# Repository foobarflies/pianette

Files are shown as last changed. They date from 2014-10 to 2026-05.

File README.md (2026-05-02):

# Pianette = Piano + Manette

A full-fledged retro-engineering of a Playstation 2 Game Pad Controller that asynchronously listens to commands from various sources (GPIO, API, etc ...) and sends Serial commands to an `ATMEGA328P` acting as a fake SPI Slave for the Console running any configured game.

_Written in Python_

You can find more info on [this article](https://tchap.me/blog/pianette/) we wrote and on the corresponding [hacknernews discussion](https://news.ycombinator.com/item?id=9071205).

## Running Pianette

`sudo` is required to have access to GPIO pins on the **Raspberry Pi B+**.

In command line, run :

    sudo -i PYTHONIOENCODING="utf-8" ./main.py --enable-source gpio --enable-source api --select-game 'street-fighter-alpha-3' --select-player 1

> The initialisation process is quite verbose to display all warnings and errors encountered.

## Adding a new game

Games are actually Python _modules_ that are imported on-demand, with a specific configuration and directory structure.

All games reside in the `config/games` directory. The following structure must be respected :

```
config/
|-- games/
|   |-- name-of-the-game/
|   |   |-- __init__.py
|   |   |-- game.py
|   |   |-- general.ini
|   |   |-- player1.py
|   |   |-- player2.py
```

`__init__.py` must be present, but it's actually just an empty file. 

`game.py` defines custom functions that may be needed to play the game. It can be empty too. It must define functions in its global scope.

Any function defined in this file will be accessible in the `game` namespace :

```python
# file : game.py
# coding: utf-8
from pianette.utils import Debug
def my_function(*args, **kwargs):
  cmd = kwargs['cmd']
  game_configobj = kwargs['config']

  Debug.println("NOTICE", "Just playing a ✕")
  cmd.onecmd("console.play ✕")
```

This function can be called with `game.my-function optional-parameter`  or `game.my_function optional-parameter` (_we prefer and encourage the first version using hyphens_).

The config files (`.ini`) must define a couple of compulsory keys :

In `general.ini` :

```ini
[Game]

[[name-of-the-game]]

# Can be empty, but the key must be defined

[[[Mappings]]]

# Can be empty, but the key must be defined
```

In `player1.ini` and `player1.ini`:

```ini
[Game]

[[name-of-the-game]]

[[[Commands]]]

# Can be empty, but the key must be defined

[[[Player 1]]]

[[[[Mappings]]]]

# Can be empty, but the key must be defined
```

> `name-of-the-game` must be the exact name of the module folder.

With this structure, you are able to select your game with `--select-game name-of-the-game`. And with the console :

    pianette: pianette.select-game name-of-the-game

## Pianette cycles

A cycle is a **single loop during which Pianette collects events from all its enabled sources to create a complete representation of a sequence of buttons that it then sends to the SPI port of the console**.

This sequence emulates a real console controller.

The timing of the sequence is fixed and has been configured to match the behavior of the console.

To replicate the "combo" functionality (i.e. playing a sequence of buttons in a deterministic order giving a result that is more interesting than the separate playing of each buttons in a row), the loop has a grace period (_configured as a number of Pianette cycles_) during which **Pianette** listens to other incoming events to decide if the current representation should wait on future events before being sent to the console.

## Available namespaces and commands

**Pianette** allows for different namespaces of commands to be used : `console`, `game`, `piano`, `pianette` and `time`.

### console

> NB : Some character replacements are available in this namespace for ease of use. Even if actual UTF-8 values are prefered when possible, you can use the replacement without affecting the functionality. 
> 
> ↑, ↓, ←, →, □, △, ✕ and ◯ can be replaced with UP, DOWN, LEFT, RIGHT, SQUARE, TRIANGLE, CROSS and CIRCLE respectively

### `console.hit`

Plays a controller button sequence for a single **Pianette** cycle.

**Example** :

    pianette: console.hit ✕ + □

**Note** : The `+` operator is used to create a synchronous sequence of buttons

### `console.play`

Plays a controller button sequence for a full **Pianette** cycle.

**Example** :

    pianette: console.play → + □

### pianette

### `pianette.enable-source`

Enables a configured source. Once enabled, **Pianette** can accept events from the source. Currently supported sources are `api` and `gpio`.

**Example** :

    pianette: pianette.enable-source gpio

### `pianette.disable-source`

Disables a previsouly enabled and configured source. Once enabled, **Pianette** cannot accept events from this source.

> An example use case is to disable the `gpio` source when running a script along side, so the user cannot disturb the script

### `pianette.select-game`

Selects an available game. If the module is not defined or the game not present, it will gracefully fails. If the module is present but that some configuration items are missing, an exception will be raised.

**Example** :

    pianette: pianette.select-game street-fighter-alpha-3

> You must give the exact module / folder name as an argument of this function

### `pianette.dump-state`

Dumps the full state of the configuration. This is mostly a debug function; it accepts no arguments.

**Example** :

    pianette: pianette.dump-state

### piano

> NB : Some character replacements are available in this namespace for ease of use. Even if actual UTF-8 values are prefered when possible, you can use the replacement without affecting the functionality. 
> 
> Specifically, ♯ and ♭ can be replaced with # and b.
> Chords aliases are also defined in the **[[Alias]]** configuration block in `piano.ini`.

### `piano.play`

Plays a chord, a pedal or a single note.

**Example** :

    pianette: piano.play C3 + E♭3 + G3

**Note** : As for the `console` namespace, the `+` operator is used to create a synchronous sequence of keys

### `piano.hold`

Holds a note, a pedal or a chord as long as `piano.release`  is not called on the same sequence. The notes will be then added to every cycle afterwards.

**Example** :

    pianette: piano.hold sostenato

### `piano.release`

Release a previously held note, pedal or chord.

**Example** :

    pianette: piano.release sostenato

> The hold and release methods are primarily used to take advantage of the pedals.

### game

This namespace is populated with the custom functions defined in `game.py` for each game module. Commands defined in the game's configuration files are also added to this namespace.

> If no game is selected, this namespace doesn't have any command available.

### time

This namespace only provides the `time.sleep {duration_in_pianette_cycles}` function that allows to pace the inputs as needed.

## The Pianette API

Pianette exposes an API

> The API is considered a source, so in order for it to work, you must enable it at launch or with the command `pianette.enable-source api`.

By default, the API base url is `http://127.0.0.1:5000/`. You can change the port in the configuration (`pianette.ini`).

### Endpoints

#### POST `/`

The endpoint is relatively simple and allows you to send any namespaced command as a POST parameter named `data`:

      curl -X POST -F 'data=console.play START + RESET' /

#### POST `/namespace/command`

This endpoint is a kind of alias for the first one. It allows you to limit the errors and send strongly-namespaced commands more easily.

      curl -X POST -F 'data=crash-nitro-kart' /pianette/select-game

### The web interface

The web interface relies on the API to work, and thus is only available when the API is enabled. It offers a backend to control pianette, as well as virtual controllers that can be used to play remotely on the console.

> In order for the web interface to work properly, the `[[Hosts]]` key of `pianette.ini` must be defined and the IP (or hostname) of the different pianette instances on the network must be set. If you only have one instance, you can define `player-1 = 127.0.0.1` only.

#### The virtual controller

The virtual controller is a #TODO

#### The admin backend

TODO

## Installation

### ATMEGA (Arduino)

The `ArduinoSPISlave.ino` sketch must be loaded onto the Arduino, connected via serial. The port is of no consequence as the program will poll the open `/dev/ttyACM*`ports and choose the first one available.

### Blacklisting

In order for SPI and i2c pins to work, it is compulsory to blacklist all modules that might be using it :

in `/etc/modprobe.d/raspi-blacklist.conf` :

    blacklist spi-bcm2708
    blacklist i2c-bcm2708

    blacklist regmap-spi
    blacklist regmap-i2c

    blacklist snd-pcm
    blacklist snd-bcm2835
    blacklist snd-seq
    blacklist snd-timer
    blacklist snd-seq-device
    blacklist snd-soc-core
    blacklist snd-soc-pcm512x
    blacklist snd-soc-wm8804
    blacklist snd-soc-bcm2708-i2s

    blacklist leds-gpio

And to remove modules at boot time in `/etc/modules`, especially sound-related modules.

### Disabling Serial port pins (UART)

In order to properly use pins `14`, `15`, and `18` that are used for `UART`, we must disable the boot up and diagnostic output to the serial port :

    sudo vi /boot/cmdline.txt

This :

    dwc_otg.lpm_enable=0 console=ttyAMA0,115200 console=tty1 root=/dev/mmcblk0p2 rootfstype=ext4 elevator=deadline rootwait fbcon=map:10 4dpi.sclk=48000000 4dpi.compress=1

becomes :

    dwc_otg.lpm_enable=0 console=tty1 root=/dev/mmcblk0p2 rootfstype=ext4 elevator=deadline rootwait fbcon=map:10 4dpi.sclk=48000000 4dpi.compress=1

Second, we need to disable the login prompt :

    sudo vi /etc/inittab

And comment out the last line :

    # Spawn a getty on Raspberry Pi serial line
    # T0:23:respawn:/sbin/getty -L ttyAMA0 115200 vt100

Let's reboot and the serial port will now be free for our exclusive use. Note that Python will still issue a `RuntimeWarning` to indicate that you are overriding the pin's default state. This is ok, and taken into account in `sources/gpio.py` anyway. 

>  Thanks to **Ted B Hale** for that : _http://raspberrypihobbyist.blogspot.fr/2012/08/raspberry-pi-serial-port.html_

### Installing needed pip packages

The necessary Python packages have been freezed, so you can install them easily with :

    pip install -r requirement.txt

And additionnally on the Pi :
    
    pip install -r requirement-rpi.txt

### Installing Pianette as a service

For ease of use, we provide a simple init script to start Pianette as a service on compatible systems :

    sudo service pianette start|stop|restart|status

See the `pianette_initd_script.sh` script, to put in `/etc/init.d/` or wherever seems adequate.

### Limitations

#### Python version

For [Flask](https://flask.palletsprojects.com/en/1.1.x/) to run correctly, we need **Python3.3.6**. It is recommended to use **pyenv** to use it, which can be installed via :

    curl -L https://raw.githubusercontent.com/yyuu/pyenv-installer/master/bin/pyenv-installer | bash

and then :

    pyenv install 3.3.6

## Team

  - **Coox** — [https://coox.org](https://coox.org)
  - **Tchap** — [https://tchap.me](https://tchap.me)

## License

**MIT**. See the [License file](https://github.com/tchapi/pianette/blob/master/LICENSE).

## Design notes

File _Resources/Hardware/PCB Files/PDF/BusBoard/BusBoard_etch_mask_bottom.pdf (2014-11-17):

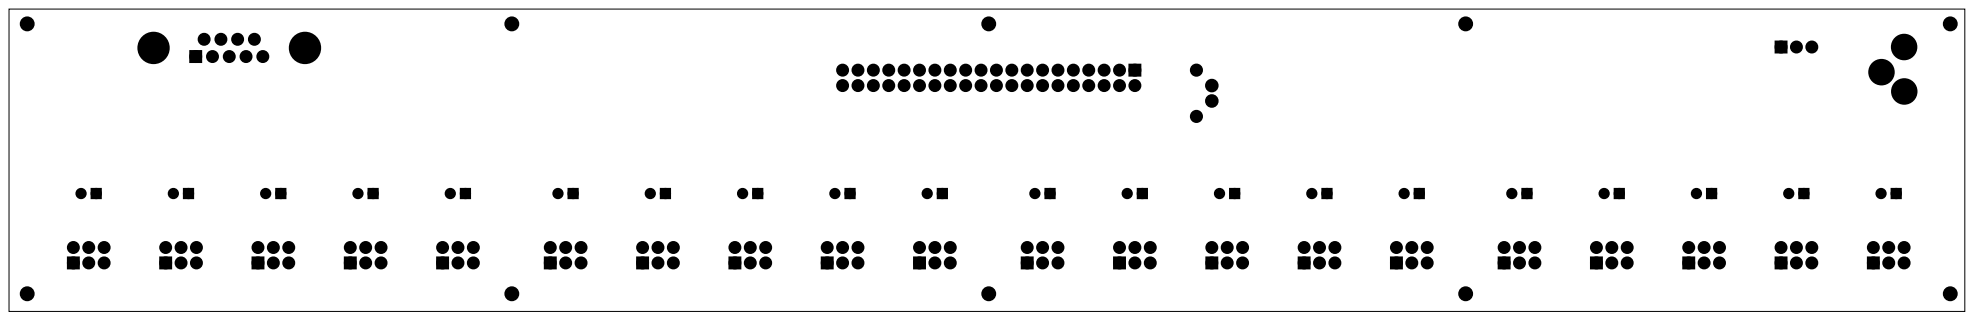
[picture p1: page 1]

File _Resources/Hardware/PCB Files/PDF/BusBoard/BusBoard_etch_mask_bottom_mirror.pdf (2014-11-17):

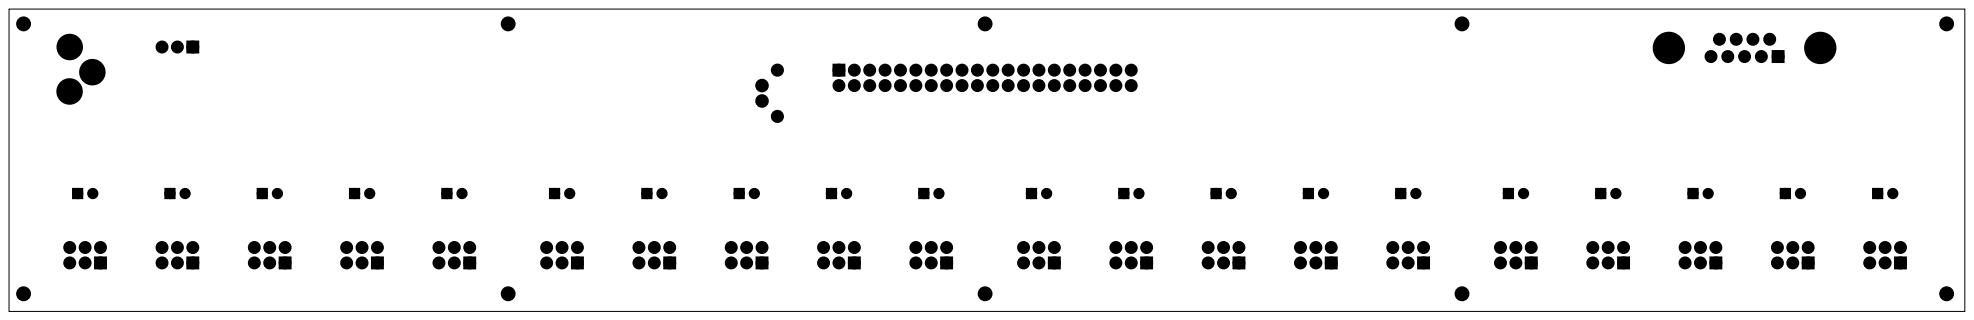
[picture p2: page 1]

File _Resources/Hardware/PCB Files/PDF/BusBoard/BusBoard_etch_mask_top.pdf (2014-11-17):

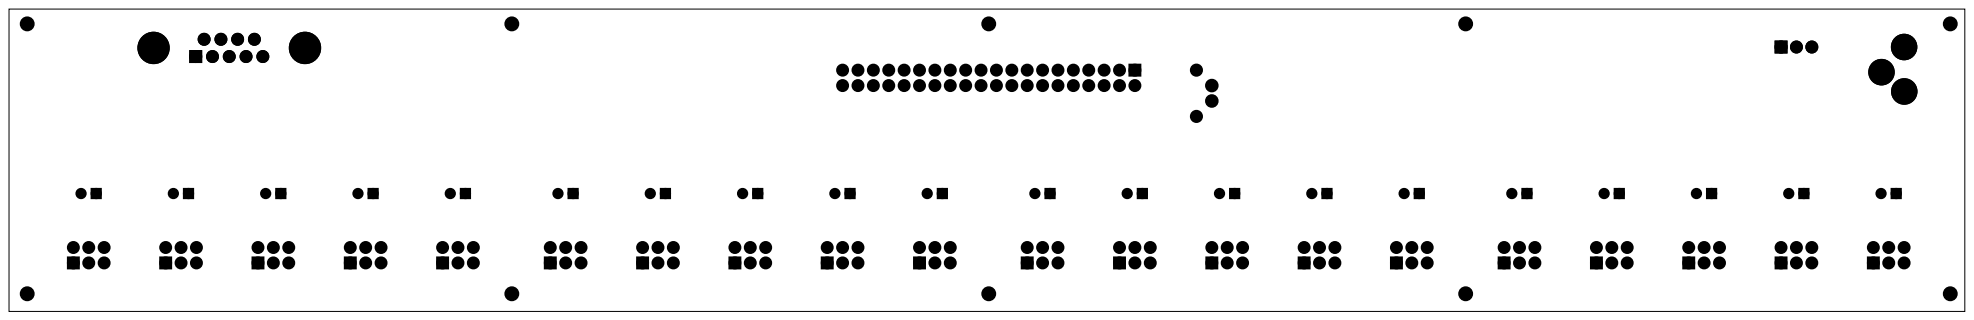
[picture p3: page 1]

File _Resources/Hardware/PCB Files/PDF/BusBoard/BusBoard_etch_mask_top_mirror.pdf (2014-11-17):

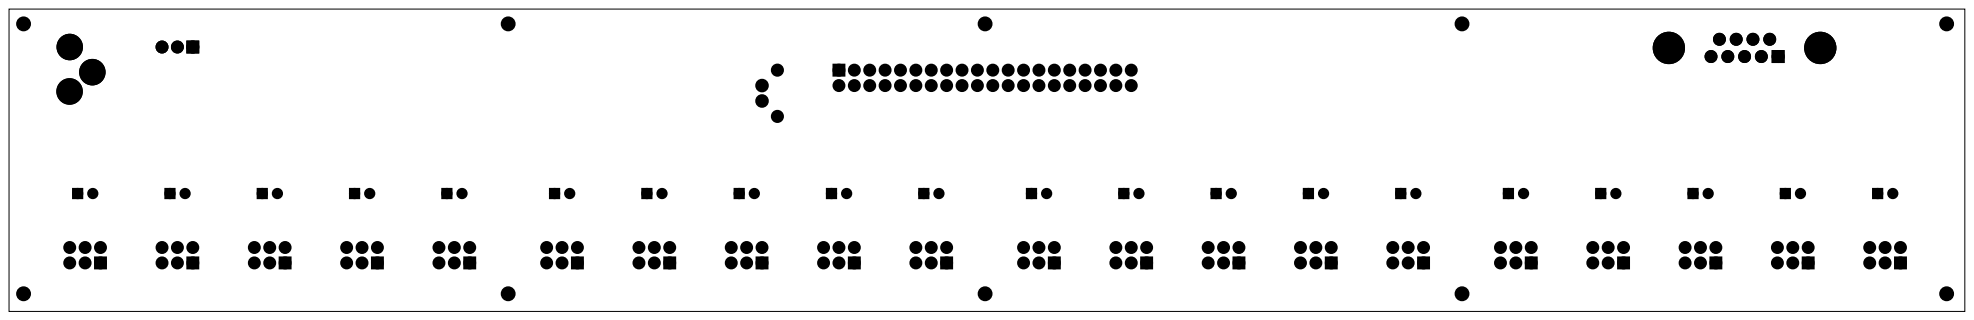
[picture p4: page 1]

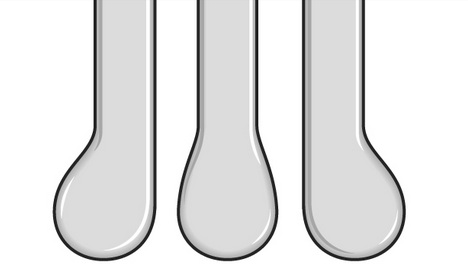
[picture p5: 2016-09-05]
_Resources/Mappings/Piano drawings/pedals.png

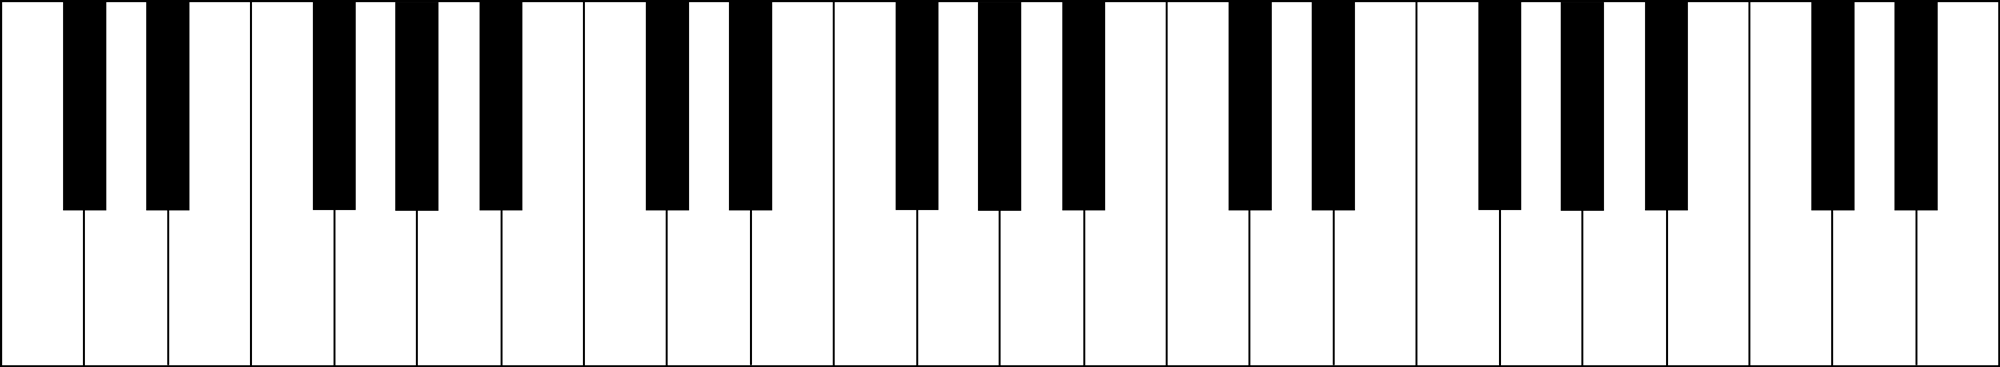
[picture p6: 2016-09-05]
_Resources/Mappings/Piano drawings/keyboard.png

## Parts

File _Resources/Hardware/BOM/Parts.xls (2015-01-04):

All products parts are listed on sparkfun.com | https://www.sparkfun.com | https://www.sparkfun.com | https://www.sparkfun.com | https://www.sparkfun.com
Description |  | Product # | Qty | Total Price
Pianette
 | Raspberry Pi B+ - GPIO Shrouded Header (2x20) | PRT-13054 | 2 | 1.52 €
 | DC Barrel Power Jack/Connector | PRT-00119 | 2 | 2.00 €
Raspberry pi
 | Raspberry Pi - Model B+ | DEV-12994 | 2 | 63.82 €
 | Raspberry Pi - Model B+ Enclosure (Clear) | DEV-12996 | 2 | 14.30 €
 | Raspberry Pi - 8GB SD Card | DEV-12998 | 2 | 19.10 €
 | Raspberry Pi B+ - GPIO Ribbon Cable (40-pin, 6") | CAB-13028 | 2 | 3.99 €
SPI Controller
 | Arduino Uno - R3 | DEV-11021 | 2 | 39.86 €
 | USB Cable A to B - 6 Foot | CAB-00512 | 2 | 6.32 €
Triggers
 | Resistor 1.0M Ohm 1/4 Watt PTH | COM-11853 | 40 | 4.47 €
 | LED - Basic Green 3mm | COM-09650 | 40 | 10.22 €
 | LED - Basic Red 3mm | COM-00533 | 40 | 10.22 €
 | Zener Diode - 5.1V 1W | COM-10301 | 40 | 7.35 €
 | Piezo Vibration Sensor - Small Vertical | SEN-09199 | 40 | 84.99 €
 | Op-Amp (Thru-Hole) - LM358 | COM-09456 | 40 | 27.48 €
 | JST Jumper 2 Wire Assembly | PRT-09914 | 40 | 27.48 €
 | Ribbon Cable - 6 wire (3ft) | CAB-10648 | 12 | 7.18 €
 | DIP Sockets Solder Tail - 8-Pin | PRT-07937 | 40 | 14.38 €
 | 2x3 Pin Shrouded Header | PRT-10877 | 80 | 86.40 €
 | Ribbon Crimp Connector - 6-pin (2x3, Female) | PRT-10651 | 80 | 20.80 €
Big red button
 | Big Dome Pushbutton - Red | COM-09181 | 1 | 7.95 €
 | Microswitch - 3-terminal | COM-09506 | 1 | 1.20 €
 |  | TOTAL |  | 461.03 €

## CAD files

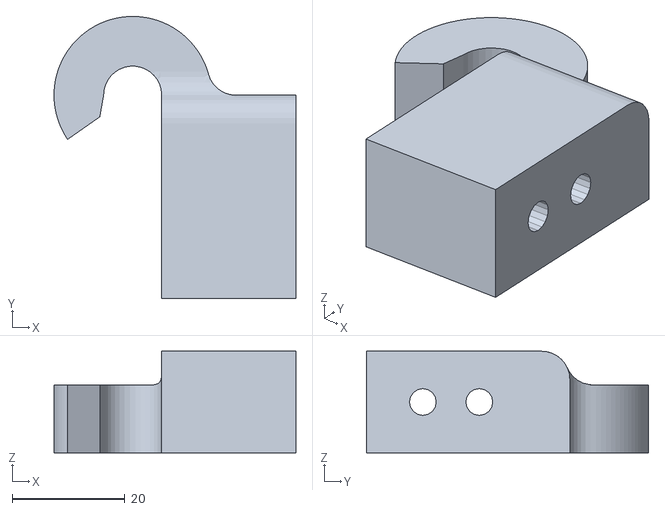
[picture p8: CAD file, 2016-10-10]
_Resources/Hardware/3D Printed parts/Piano/STL/Export_WEBER_Left.stl
42.9 x 50.0 x 18.0

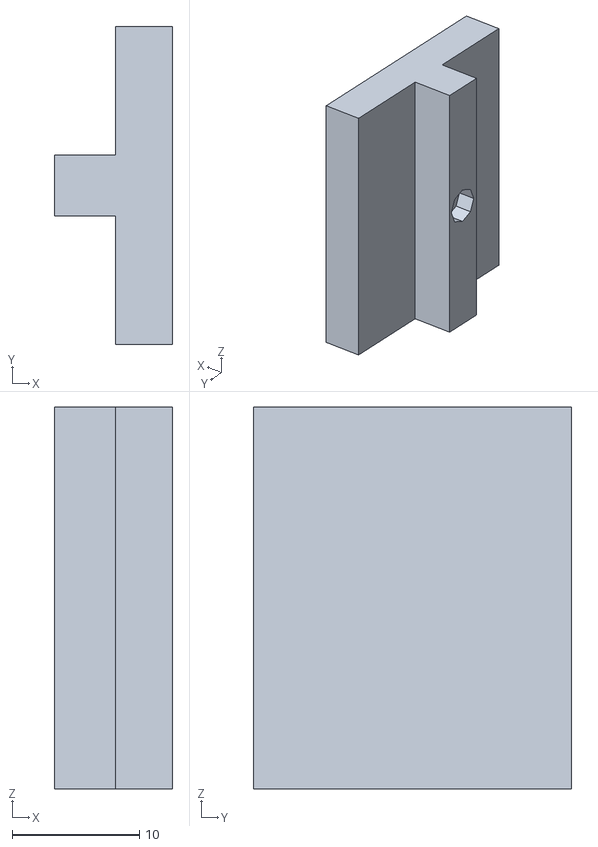
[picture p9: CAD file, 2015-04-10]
_Resources/Hardware/3D Printed parts/Piano/STL/Other pianos/cale_5mm.stl
9.30 x 25.0 x 30.0

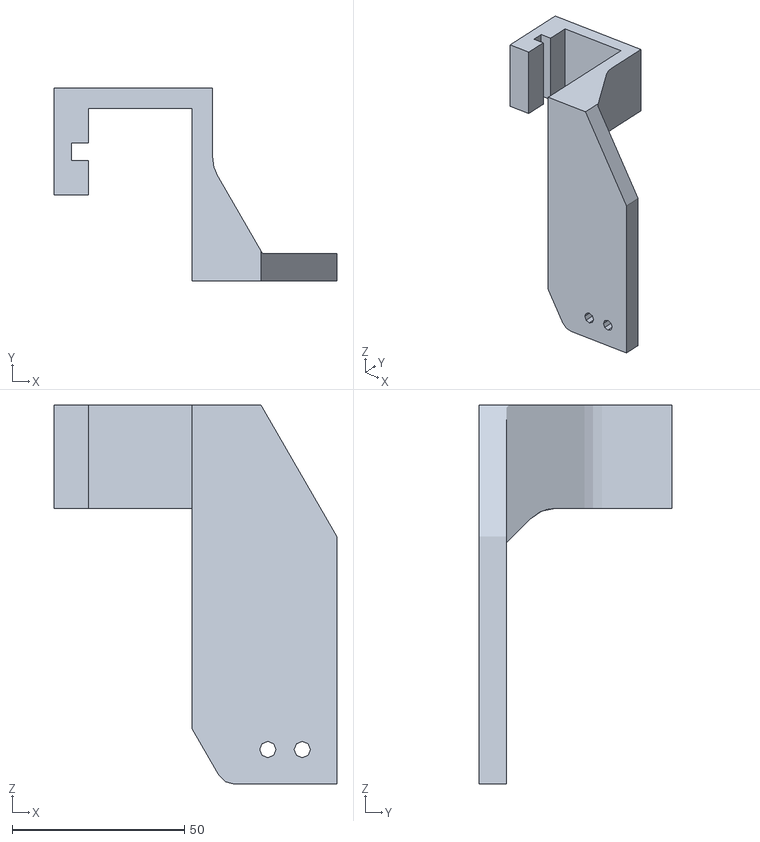
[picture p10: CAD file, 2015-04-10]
_Resources/Hardware/3D Printed parts/Piano/STL/Other pianos/piano_right.stl
82.0 x 56.0 x 110.0

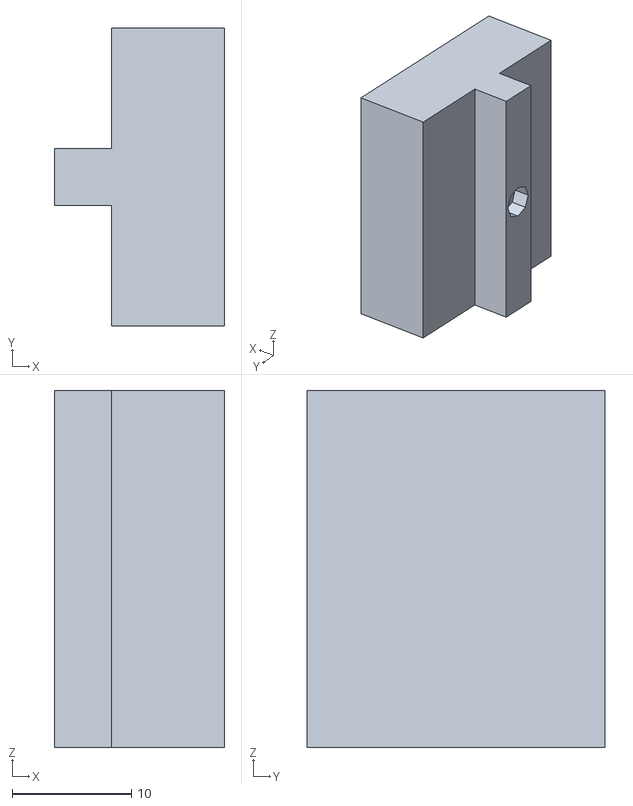
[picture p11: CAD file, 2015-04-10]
_Resources/Hardware/3D Printed parts/Piano/STL/Other pianos/cale_10mm.stl
14.3 x 25.0 x 30.0

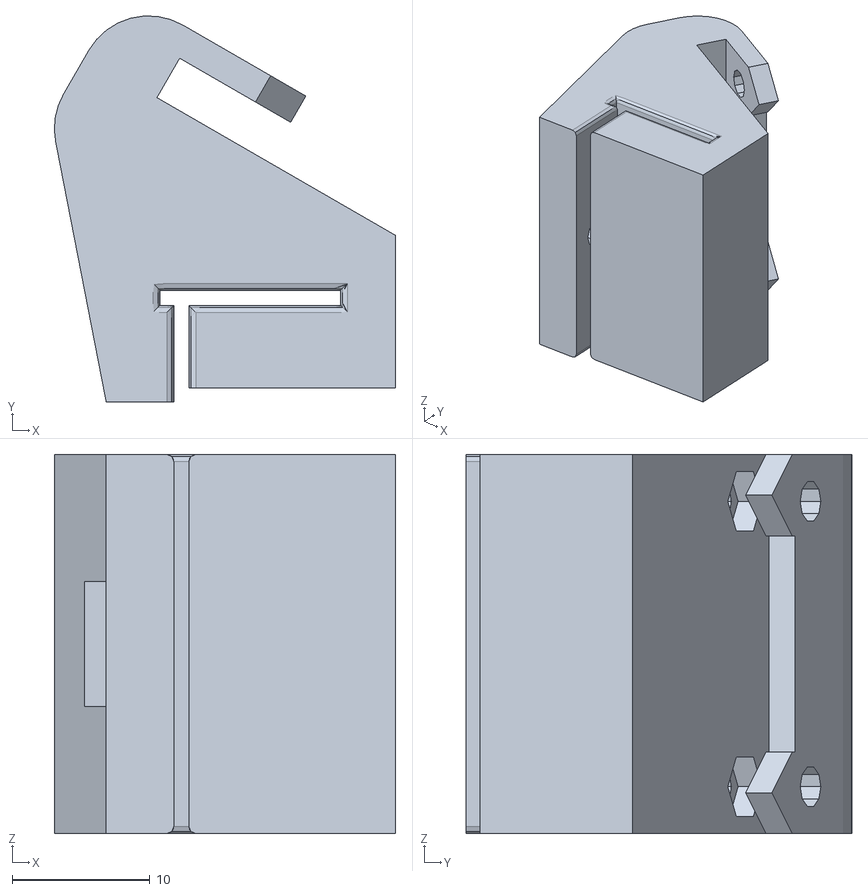
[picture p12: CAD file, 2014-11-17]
_Resources/Hardware/3D Printed parts/Piano/STL/Slider.stl
24.8 x 28.0 x 27.5

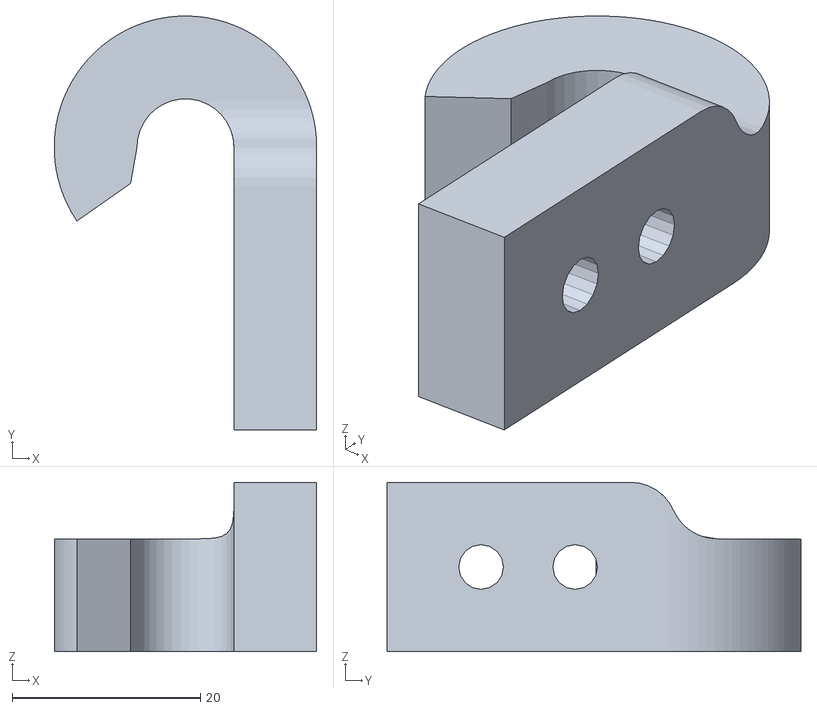
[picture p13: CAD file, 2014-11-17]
_Resources/Hardware/3D Printed parts/Piano/STL/Left Hook.stl
27.9 x 44.0 x 18.0

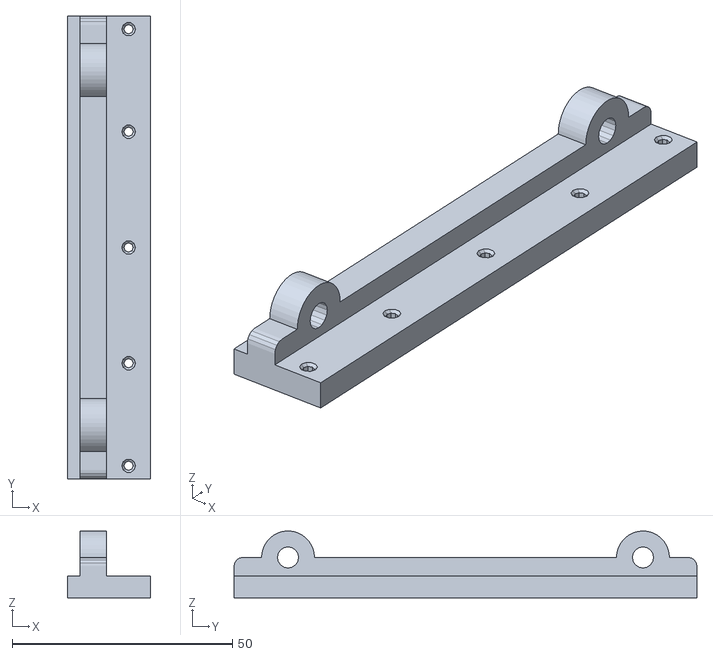
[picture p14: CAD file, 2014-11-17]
_Resources/Hardware/3D Printed parts/Piano/STL/Pianette Holder.stl
18.9 x 105.0 x 15.2

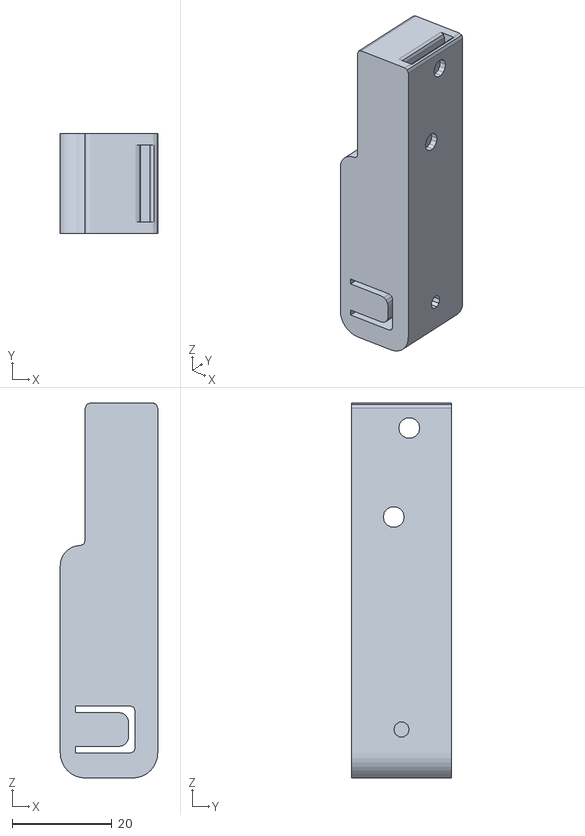
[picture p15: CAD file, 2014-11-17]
_Resources/Hardware/3D Printed parts/Piano/STL/Rail Holder.stl
19.5 x 20.0 x 75.0

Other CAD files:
_Resources/Hardware/3D Printed parts/Piano/STL/Export_WEBER_Right.stl
_Resources/Hardware/3D Printed parts/Piano/STL/Right Hook.stl
_Resources/Hardware/3D Printed parts/Piano/Hooks_Weber.CATPart

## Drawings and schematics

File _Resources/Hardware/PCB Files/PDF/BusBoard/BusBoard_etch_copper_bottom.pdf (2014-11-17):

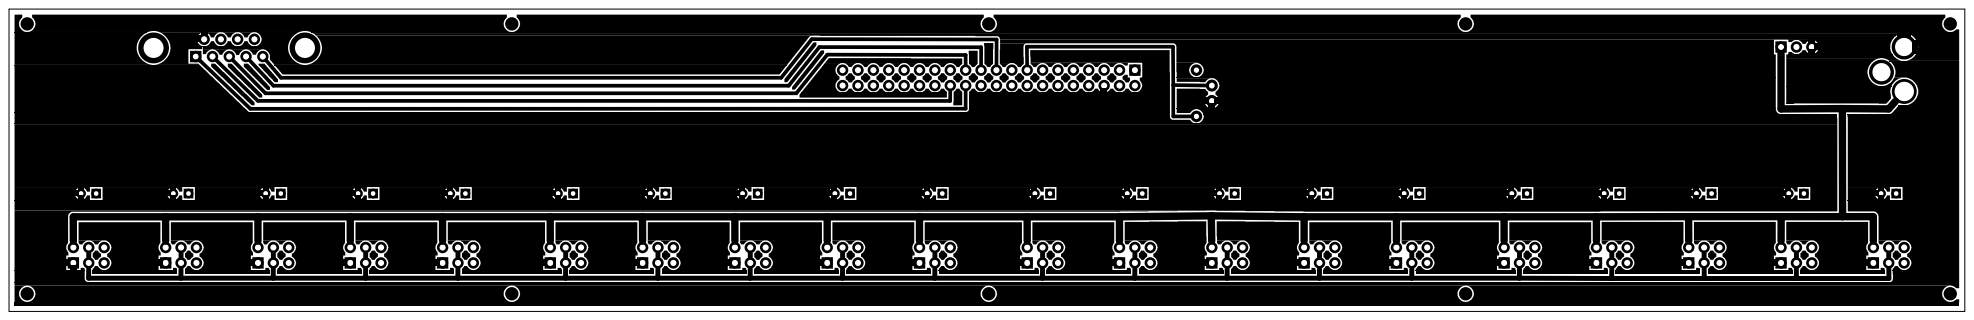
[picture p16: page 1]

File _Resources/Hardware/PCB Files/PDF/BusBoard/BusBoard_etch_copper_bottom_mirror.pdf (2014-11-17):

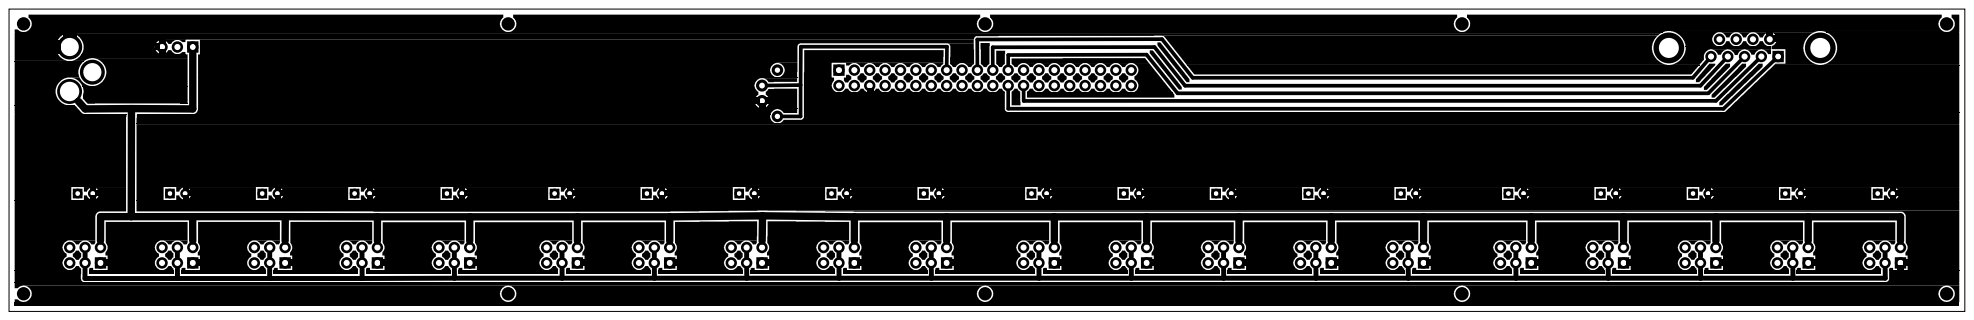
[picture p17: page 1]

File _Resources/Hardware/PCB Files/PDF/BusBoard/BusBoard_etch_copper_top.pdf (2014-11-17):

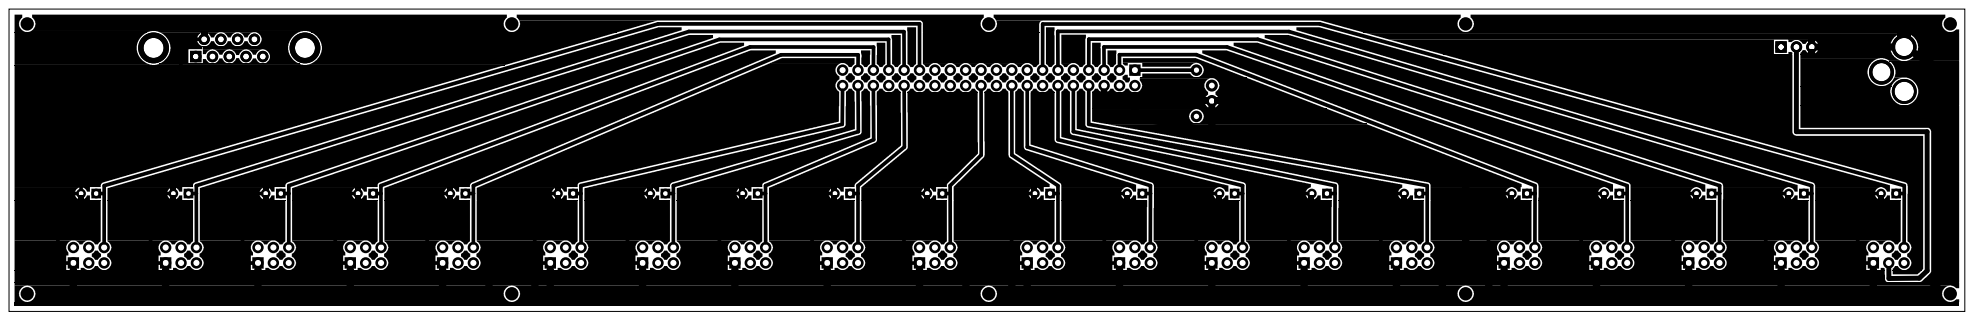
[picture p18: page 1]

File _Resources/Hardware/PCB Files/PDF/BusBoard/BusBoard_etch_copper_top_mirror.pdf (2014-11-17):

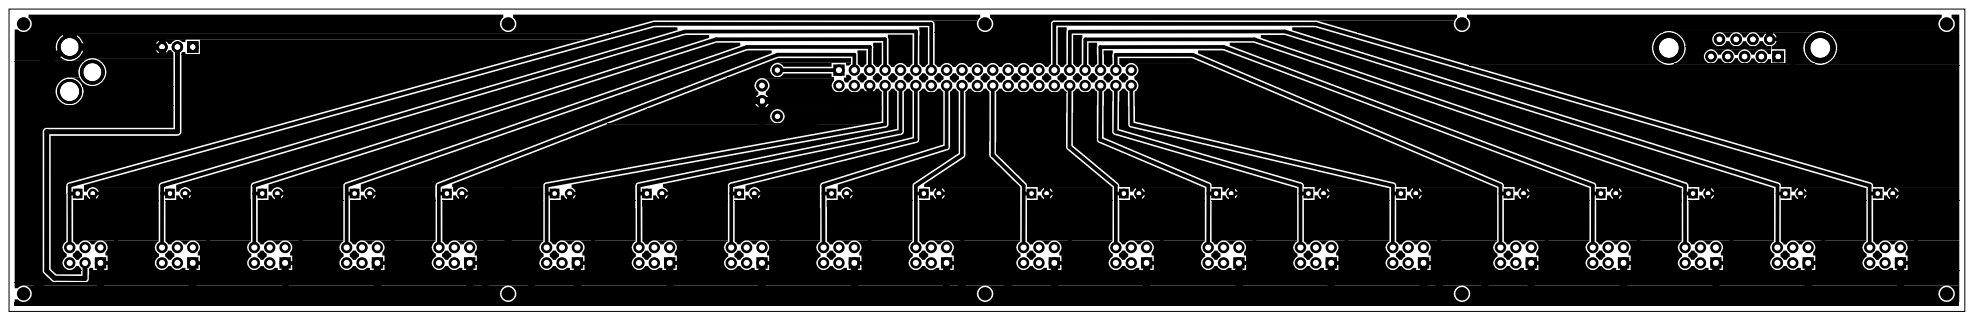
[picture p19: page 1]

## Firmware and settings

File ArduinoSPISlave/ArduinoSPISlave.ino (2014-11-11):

/*

Arduino SPI Slave for Playstation 2

Based on busslave's work form 2012
 
Arduino pin |  AVR pin | PSX pin

9 PB1       |    15    | 9 ACK     (green)
10 -SS      |    16    | 6 ATT     (yellow)
11 MOSI     |    17    | 2 COMMAND (orange)
12 MISO     |    18    | 1 DATA    (brown)
13 SCK      |    19    | 7 CLOCK   (blue)
                       | 4 GND
*/

#include "Arduino.h"
#include <avr/io.h>
#include <avr/interrupt.h>
#include <util/delay.h>

#define F_CPU 16000000
#define ARDUINO 101

#define SPI_PORT PORTB
#define SPI_PINS PINB
#define SPI_DDR  DDRB
#define SPI_PINS  PINB

#define ACK_PIN   1 //PB1
#define ATT_PIN   2 //~SS
#define CMD_PIN   3 //MOSI
#define DATA_PIN  4 //MISO
#define CLK_PIN   5 //SCK

#define DATA_LEN 5

#define LED_PIN 7

#define _DEBUG 0

char control_data[2] = {0xFF,0xFF};

volatile uint8_t data_buff[DATA_LEN]={0x41,0x5A,0xFF,0xFF,0xFF}; // Reply: nothing pressed.
volatile uint8_t command_buff[DATA_LEN]={0x01,0x42,0x00,0x00,0x00};
    
volatile uint8_t curr_byte=0;
volatile uint8_t next_byte=0;

void setup();
void loop();

void setup() {
  
  // Begin Serial communication with Pi
  Serial.begin(38400);
    
  //SPI_PORT setup. 
  SPI_DDR |= (1<<ACK_PIN); // output
  SPI_PORT |= (1<<ACK_PIN); // set HIGH
  SPI_DDR |= (1<<DATA_PIN); // output
  SPI_PORT |= (1<<DATA_PIN); // set HIGH  
  
  //SPI setup.
  PRR &= ~(1<<PRSPI);  // Set to 0 to ensure power to SPI module.
  SPSR|=(1<<SPI2X);    // Fosc/32. @16MHz==500KHz.
  //SPCR|=(1<<SPR1);   // Fosc/64. @16MHz==250KHz.
  SPCR|=(1<<CPHA);     // Setup @ leading edge, sample @ falling edge.
  SPCR|=(1<<CPOL);     // Leading edge is falling edge, trailing edge is rising edge.
  SPCR &= ~(1<<MSTR);  // MSTR bit is zero, SPI is slave.
  SPCR|=(1<<DORD);     // Byte is transmitted LSB first, MSB last.
  SPCR|=(1<<SPE);      // Enable SPI.
  SPCR|=(1<<SPIE);     // Enable Serial Transfer Complete (STC) interrupt.
  SPDR=0xFF;
  
  sei(); // Enable global interrupts.

  // Indicate Reset
  pinMode(LED_PIN, OUTPUT);
  digitalWrite(LED_PIN, HIGH);
  delay(500);
  digitalWrite(LED_PIN, LOW);
  delay(70);
  digitalWrite(LED_PIN, HIGH);
  delay(70);
  digitalWrite(LED_PIN, LOW);
  delay(70);
  digitalWrite(LED_PIN, HIGH);
  delay(70);
  digitalWrite(LED_PIN, LOW);
  delay(70);
  digitalWrite(LED_PIN, HIGH);
  delay(70);
  digitalWrite(LED_PIN, LOW);

  if (_DEBUG) {
    Serial.println("");
    Serial.println("-----------------------------------");
    Serial.println("Playstation 2 Protocol initialized.");
    Serial.println("-----------------------------------");
  }

}

/* SPI interrupt */
ISR(SPI_STC_vect) { 

  // Byte received from the master
  uint8_t inbyte = SPDR;
  
  // FIX ME : Manage other cases ? (other commands from the master?)
  if (inbyte == command_buff[curr_byte]) {

    // We put the next byte in the buffer, to be send along the next clock cycle
    SPDR = data_buff[curr_byte];
    curr_byte++;
    
    // We need to ACK (PS2 Protocol)
    if (curr_byte < DATA_LEN) { // ACK goes low.
      SPI_PORT &= ~(1<<PORTB1);
      _delay_us(10); // For 10µseconds
      SPI_PORT |= (1<<PORTB1);
    } else { // Except for the last packet
      SPDR = 0xFF;
      curr_byte = 0;
    }

  } else {
    
    SPDR = 0xFF;
    curr_byte = 0;
  
  }
  
}

void loop() {

  /* Reads input from Serial connection */
  /*
    We're going to read 2 characters = 2 x 1 byte
    It's going to be read as a char but then translated
    to HEX, taking only the lower byte
  */

  if (Serial.available() >= 2) {
    
    Serial.readBytes(control_data, 2); // Read 16 bits

    // DEBUG 
    if (_DEBUG) {
      Serial.print("Command : 0x");
      Serial.print(lowByte(control_data[0]), HEX);
      Serial.print(" 0x");
      Serial.print(lowByte(control_data[1]), HEX);
      Serial.println("");
    }

    // We store the new commands in the data_buff buffer
    data_buff[2] = lowByte(control_data[0]);
    data_buff[3] = lowByte(control_data[1]);

    // Led
    if (lowByte(control_data[0]) != 255 || lowByte(control_data[1]) != 255){
      digitalWrite(LED_PIN, HIGH);
    } else {
      digitalWrite(LED_PIN, LOW);
    }
    
  }

}

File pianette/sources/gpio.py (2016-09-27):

# coding: utf-8

import pianette.errors
import re
import time
import warnings

from pianette.utils import Debug

import RPi.GPIO

RPi.GPIO.setwarnings(True)
RPi.GPIO.cleanup()

class GPIOConfigUtil:

    # Channels

    CHANNEL_LABELING_BCM = "BCM"

    supported_channel_labelings = [ CHANNEL_LABELING_BCM ]

    @staticmethod
    def is_supported_channel_labeling(channel_labeling):
        return channel_labeling in GPIOConfigUtil.supported_channel_labelings

    rpi_gpio_mode_for_channel_labeling = {
        CHANNEL_LABELING_BCM: RPi.GPIO.BCM,
    }

    @staticmethod
    def get_rpi_gpio_mode_for_channel_labeling(channel_labeling):
        if not GPIOConfigUtil.is_supported_channel_labeling(channel_labeling):
            raise PianetteGPIOConfigError("Unsupported GPIO channel labeling '%s'" % (channel_labeling))

        if channel_labeling not in GPIOConfigUtil.rpi_gpio_mode_for_channel_labeling.keys():
            raise PianetteGPIOConfigError("Undefined GPIO mode for channel labeling '%s'" % (channel_labeling))

        return GPIOConfigUtil.rpi_gpio_mode_for_channel_labeling.get(channel_labeling, None)

    @staticmethod
    def get_rpi_gpio_channel(channel, channel_labeling):
        if not GPIOConfigUtil.is_supported_channel_labeling(channel_labeling):
            raise PianetteGPIOConfigError("GPIO channel labeling '%s' is not supported" % (channel_labeling))

        rpi_gpio_channel = None

        if channel_labeling == GPIOConfigUtil.CHANNEL_LABELING_BCM:
            match = re.search('GPIO(?P<rpi_gpio_channel>\d+)', channel)
            if match:
                rpi_gpio_channel = int(match.group('rpi_gpio_channel'))

        if rpi_gpio_channel is None:
            raise PianetteConfigError("Undefined RPi.GPIO channel for channel '%s' using labeling '%s'" % (channel, channel_labeling))

        return rpi_gpio_channel

    # Resistors

    RESISTOR_PULL_DOWN = "pull-down"
    RESISTOR_PULL_UP = "pull-up"
    RESISTOR_NONE = "none"

    supported_resistors = [ RESISTOR_PULL_DOWN, RESISTOR_PULL_UP, RESISTOR_NONE ]

    @staticmethod
    def is_supported_resistor(resistor):
        return resistor in GPIOConfigUtil.supported_resistors

    rpi_gpio_pull_up_down_for_resistor = {
        RESISTOR_PULL_DOWN: RPi.GPIO.PUD_DOWN,
        RESISTOR_PULL_UP: RPi.GPIO.PUD_UP,
        RESISTOR_NONE: None,
    }

    @staticmethod
    def get_rpi_gpio_pull_up_down_for_resistor(resistor):
        if not GPIOConfigUtil.is_supported_resistor(resistor):
            raise PianetteGPIOConfigError("Unsupported GPIO resistor '%s'" % (resistor))

        if resistor not in GPIOConfigUtil.rpi_gpio_pull_up_down_for_resistor.keys():
            raise PianetteGPIOConfigError("Undefined GPIO pull-up-down for resistor '%s'" % (resistor))

        return GPIOConfigUtil.rpi_gpio_pull_up_down_for_resistor.get(resistor, None)

    # Events

    EVENT_FALLING = "Falling"
    EVENT_RISING = "Rising"

    supported_events = [ EVENT_FALLING, EVENT_RISING ]

    @staticmethod
    def is_supported_event(event):
        return event in GPIOConfigUtil.supported_events

    rpi_gpio_event_for_event = {
        EVENT_FALLING: RPi.GPIO.FALLING,
        EVENT_RISING: RPi.GPIO.RISING,
    }

    @staticmethod
    def get_rpi_gpio_event_for_event(event):
        if not GPIOConfigUtil.is_supported_event(event):
            raise PianetteGPIOConfigError("Unsupported GPIO event '%s'" % (event))

        if event not in GPIOConfigUtil.rpi_gpio_event_for_event.keys():
            raise PianetteGPIOConfigError("Undefined GPIO event for event '%s'" % (event))

        return GPIOConfigUtil.rpi_gpio_event_for_event.get(event, None)

    # Polling

    POLLING_STATUS_HIGH = "High"
    POLLING_STATUS_LOW = "Low"

    supported_polling_statuses = [ POLLING_STATUS_HIGH, POLLING_STATUS_LOW ]

    @staticmethod
    def is_supported_polling_status(polling_status):
        return polling_status in GPIOConfigUtil.supported_polling_statuses

    rpi_gpio_input_for_polling_status = {
        POLLING_STATUS_HIGH: RPi.GPIO.HIGH,
        POLLING_STATUS_LOW: RPi.GPIO.LOW,
    }

    @staticmethod
    def get_rpi_gpio_input_for_polling_status(polling_status):
        if not GPIOConfigUtil.is_supported_polling_status(polling_status):
            raise PianetteGPIOConfigError("Unsupported GPIO polling status '%s'" % (polling_status))

        if polling_status not in GPIOConfigUtil.rpi_gpio_input_for_polling_status.keys():
            raise PianetteGPIOConfigError("Undefined GPIO input for polling status '%s'" % (polling_status))

        return GPIOConfigUtil.rpi_gpio_input_for_polling_status.get(polling_status, None)

    POLLING_EVENT_FALLING = "Falling"
    POLLING_EVENT_RISING = "Rising"

    supported_polling_events = [ POLLING_EVENT_FALLING, POLLING_EVENT_RISING ]

    @staticmethod
    def is_supported_polling_event(polling_event):
        return polling_event in GPIOConfigUtil.supported_polling_events
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

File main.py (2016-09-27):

#!/usr/bin/env python3

# Pianette

# A command-line emulator of a PS2 Game Pad Controller 
# that asynchronously listens to GPIO EDGE_RISING
# inputs from sensors and sends Serial commands to 
# an ATMEGA328P acting as a fake SPI Slave for the Console.

# Written in Python 3.

import importlib
import pianette.config
import sys

from pianette.Pianette import Pianette
from pianette.PianetteArgumentParser import PianetteArgumentParser
from pianette.utils import Debug

Debug.println("INFO", " ")
Debug.println("INFO", " ################################## ")
Debug.println("INFO", " |            PIANETTE            | ")
Debug.println("INFO", " ################################## ")
Debug.println("INFO", " ")

configobj = pianette.config.get_all_configobj()

parser = PianetteArgumentParser(configobj=configobj)
args = parser.parse_args()

# Instanciate the global Pianette
# Its responsibility is to translate Piano actions to Console actions
pianette = Pianette(configobj=configobj)

# We MUST select a player before we select a game.
# This allow for per-player mappings
# The game can be changed afterwards, but not the player, as we don't expect
# to be able to unplug the controller from the console.
pianette.select_player(args.selected_player)
pianette.select_game(args.selected_game)

if args.enabled_sources is not None:
    for source in args.enabled_sources:
        pianette.load_source(source)

# Run the main loop of interactive Pianette
Debug.println("NOTICE", "Entering main loop")
pianette.cmd.cmdloop()

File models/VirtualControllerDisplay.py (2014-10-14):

from utils import *
from tkinter import *

class VirtualControllerDisplay(Frame):

  def __init__(self, base, stateController):
    super(VirtualControllerDisplay, self).__init__(base)

    self.stateController = stateController
    self.base = base # appWindow

    self.grid()
    self.createButtons()
    self.createUtilityButtons()
    Debug.println("SUCCESS", "Gui created.")

  def createUtilityButtons(self):
# Quit button
    self.BUTTON_QUIT = Button(self)
    self.BUTTON_QUIT["text"] = "Quit"
    self.BUTTON_QUIT["command"] = lambda: self.base.destroy()
    self.BUTTON_QUIT.grid(row=7, column=5)

# Reset button
    self.BUTTON_RESET = Button(self)
    self.BUTTON_RESET["text"] = "Reset"
    self.BUTTON_RESET["command"] = lambda: self.buttonAction("RESET")  
    self.BUTTON_RESET.grid(row=7, column=6)

# Label for commands
    self.LABEL_CMD = Label(self)
    self.LABEL_CMD["text"] = "..."
    self.LABEL_CMD["relief"] = SUNKEN
    self.LABEL_CMD["font"] = ('Helvetica', '16')
    self.LABEL_CMD.grid(row=1, column=5	, columnspan=2, padx=1, pady=1, sticky="we")

# Placeholder for swag
    self.LABEL_PLACEHOLDER = Label(self)
    self.LABEL_PLACEHOLDER["text"] = "  "
    self.LABEL_PLACEHOLDER.grid(row=0, column=4	, columnspan=2)

# Placeholder for swag
    self.LABEL_PLACEHOLDER = Label(self)
    self.LABEL_PLACEHOLDER["text"] = "  "
    self.LABEL_PLACEHOLDER.grid(row=2, column=4	, columnspan=2)

# Placeholder for swag
    self.LABEL_PLACEHOLDER = Label(self)
    self.LABEL_PLACEHOLDER["text"] = "  "
    self.LABEL_PLACEHOLDER["font"] = ('Helvetica', '30')
    self.LABEL_PLACEHOLDER.grid(row=6, column=4	, columnspan=2)

  def createButtons(self):

# O Button
    self.BUTTON_O = Button(self)
    self.BUTTON_O["bg"] = "darkGray"
    self.BUTTON_O["activebackground"] = "darkGray"
    self.BUTTON_O["fg"] = "red"
    self.BUTTON_O["height"] = 1
    self.BUTTON_O["width"] = 1
    self.BUTTON_O["text"] = "◯"
    self.BUTTON_O["command"] = lambda: self.buttonAction("O")
    self.BUTTON_O.grid(row=4, column=9)
# X Button
    self.BUTTON_X = Button(self)
    self.BUTTON_X["bg"] = "darkGray"
    self.BUTTON_X["activebackground"] = "darkGray"
    self.BUTTON_X["fg"] = "blue"
    self.BUTTON_X["height"] = 1
    self.BUTTON_X["width"] = 1
    self.BUTTON_X["text"] = "✕"
    self.BUTTON_X["command"] = lambda: self.buttonAction("X")
    self.BUTTON_X.grid(row=5, column=8)
# TRIANGLE Button
    self.BUTTON_T = Button(self)
    self.BUTTON_T["bg"] = "darkGray"
    self.BUTTON_T["activebackground"] = "darkGray"
    self.BUTTON_T["fg"] = "green"
    self.BUTTON_T["height"] = 1
    self.BUTTON_T["width"] = 1
    self.BUTTON_T["text"] = "△"
    self.BUTTON_T["command"] = lambda: self.buttonAction("T")
    self.BUTTON_T.grid(row=3, column=8)
# SQUARE Button
    self.BUTTON_S = Button(self)
    self.BUTTON_S["bg"] = "darkGray"
    self.BUTTON_S["activebackground"] = "darkGray"
    self.BUTTON_S["fg"] = "pink"
    self.BUTTON_S["height"] = 1
    self.BUTTON_S["width"] = 1
    self.BUTTON_S["text"] = "▢"
    self.BUTTON_S["command"] = lambda: self.buttonAction("S")
    self.BUTTON_S.grid(row=4, column=7)

# Movement Buttons
    self.BUTTON_LEFT = Button(self)
    self.BUTTON_LEFT["bg"] = "darkSlateGray"
    self.BUTTON_LEFT["activebackground"] = "darkSlateGray"
    self.BUTTON_LEFT["height"] = 1
    self.BUTTON_LEFT["width"] = 1
    self.BUTTON_LEFT["text"] = "◀"
    self.BUTTON_LEFT["command"] = lambda: self.buttonAction("LEFT")
    self.BUTTON_LEFT.grid(row=4, column=1)
    self.BUTTON_RIGHT = Button(self)
    self.BUTTON_RIGHT["bg"] = "darkSlateGray"
    self.BUTTON_RIGHT["activebackground"] = "darkSlateGray"
    self.BUTTON_RIGHT["height"] = 1
    self.BUTTON_RIGHT["width"] = 1
    self.BUTTON_RIGHT["text"] = "▶"
    self.BUTTON_RIGHT["command"] = lambda: self.buttonAction("RIGHT")
    self.BUTTON_RIGHT.grid(row=4, column=3)
    self.BUTTON_UP = Button(self)
    self.BUTTON_UP["bg"] = "darkSlateGray"
    self.BUTTON_UP["activebackground"] = "darkSlateGray"
    self.BUTTON_UP["height"] = 1
    self.BUTTON_UP["width"] = 1
    self.BUTTON_UP["text"] = "▲"
    self.BUTTON_UP["command"] = lambda: self.buttonAction("UP")
    self.BUTTON_UP.grid(row=3, column=2)
    self.BUTTON_DOWN = Button(self)
    self.BUTTON_DOWN["bg"] = "darkSlateGray"
    self.BUTTON_DOWN["activebackground"] = "darkSlateGray"
    self.BUTTON_DOWN["height"] = 1
    self.BUTTON_DOWN["width"] = 1
    self.BUTTON_DOWN["text"] = "▼"
    self.BUTTON_DOWN["command"] = lambda: self.buttonAction("DOWN")
    self.BUTTON_DOWN.grid(row=5, column=2)

# Select and Start
    self.FRAME_MIDDLE = Frame(self)
    self.FRAME_MIDDLE.grid(row=4, column=5, columnspan=2, sticky="we")
    self.FRAME_MIDDLE.grid_propagate(0)

    self.BUTTON_START = Button(self.FRAME_MIDDLE)
    self.BUTTON_START["bg"] = "grey"
    self.BUTTON_START["activebackground"] = "grey"
    self.BUTTON_START["fg"] = "white"
    self.BUTTON_START["height"] = 1
    self.BUTTON_START["text"] = "START"
    self.BUTTON_START["font"] = ('Helvetica', '7')
    self.BUTTON_START["command"] = lambda: self.buttonAction("START")
    self.BUTTON_START.pack(side=LEFT)
    self.BUTTON_SELECT = Button(self.FRAME_MIDDLE)
    self.BUTTON_SELECT["bg"] = "grey"
    self.BUTTON_SELECT["activebackground"] = "grey"
    self.BUTTON_SELECT["fg"] = "white"
    self.BUTTON_SELECT["height"] = 1
    self.BUTTON_SELECT["text"] = "SEL"
    self.BUTTON_SELECT["font"] = ('Helvetica', '7')
    self.BUTTON_SELECT["command"] = lambda: self.buttonAction("SELECT")
    self.BUTTON_SELECT.pack(side=LEFT)
 
  def buttonAction(self, command):
    Debug.println("NOTICE", "Button %s activated from GUI" % command)
    self.stateController.raiseFlag(command)
    self.updateLabel(command)
    self.flashButton(command)

  def getButtonForCommand(self, command):

    buttons = { "O" : self.BUTTON_O,
                "X" : self.BUTTON_X,
                "T" : self.BUTTON_T,
                "S" : self.BUTTON_S,
                "SELECT" : self.BUTTON_SELECT,
                "START" : self.BUTTON_START,
                "LEFT" : self.BUTTON_LEFT,
                "RIGHT" : self.BUTTON_RIGHT,
                "UP" : self.BUTTON_UP,
                "DOWN" : self.BUTTON_DOWN,
                "RESET" : self.BUTTON_RESET,
              }

    return buttons[command]

  def updateLabel(self, command):
    self.LABEL_CMD["text"] = command
    self.base.update()

  def flashButton(self, command):
    button = self.getButtonForCommand(command)
    button.flash()

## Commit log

2014-09-30 Add a controller for GPIO pins Add the button.flash() stuff Only for testing purposes now WIP
2014-10-11 Fixup - testing !!!
    [ConsoleController.py]
2014-10-11 Fixups New paradigm to control the console with an Arduino
    WIP
    [ArduinoSPISlave.ino, ConsoleController.py, ControllerState.py]
2014-10-12 Improve Arduino Sketch for byte receiving Re-add ConsoleController for sending commands
    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
2014-10-13 fix more various errors
    [ConsoleController.py]
2014-10-13 permanently send controller state in a thread
2014-10-13 Remove "reset to nothing pressed" in code Pi will take care of timing
    [ArduinoSPISlave.ino]
2014-10-14 Allow None serial ports More info printouts
2014-10-14 Better debug printouts Fixups
    [ConsoleController.py, ControllerState.py, ControllerStateTimedBuffer.py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]
2014-10-14 Adding utils and debug.println
2014-10-17 clarify PSX button vs. direction symbols
2014-10-19 move the console controller inside the pianette
    One less thread to worry about!
2014-10-20 Add some warnings for Pins already attached ... especially UART
    Fixups
    [ConsoleController.py, ControllerState.py, GPIOController.py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]
2014-10-23 Add LED for final board
2014-10-23 Add update script for ease of use Correct some import stuff
    [Pianette.py, main-nogui.py]
2014-10-24 fix bogus property lookup
    [Pianette.py]
2014-10-24 add support for L1/R1, L2/R2 buttons
2014-10-24 fix bogus note name
    [PianoState.py]
2014-10-24 bugfix: psx state must clear on combo interrupt
    [Pianette.py]
2014-10-25 More fixup for player number Change gpio_check for less verbosity
    [GPIOController.py, main-nogui.py]
2014-10-28 Add B♭1 for Jumping
2014-11-10 Change pin 02 assignment
2014-11-10 disable gpio during big red button sequence
2014-11-10 explore big red button sequence
2014-11-10 Improve timing for red button
2014-11-11 New way of hitting button (TEST)
2014-11-11 Test not concluant for red button
2014-11-17 Add resources - first versions
    [AnalogTrigger.fzz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]
2014-11-17 New version of the PCB, git style
    [BusBoard.fzz, BusBoard_v2.fzz]
2014-11-17 New version of the bus board with pull-up resistor
    [BusBoard_copperBottom.gbl, BusBoard_copperTop.gtl, BusBoard_maskBottom.gbs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]
2015-01-04 Added parts list on sparkfun
    [Parts.xls]
2015-04-10 Add parts to fit other pianos These parts hook up to the top of the piano left and right panels, and allow a small (+/- 10mm) adjustement to fit different brands and makes.
    [cale_10mm.stl, cale_5mm.stl, piano_right.stl]
2016-09-03 Update .gitignore
    PIANETTE IS BACK 💥
2016-09-03 Specify required packages, with Raspberry Pi section
2016-09-03 Do not crash on empty command line
    [PianetteCmd.py]
2016-09-04 Fix device scale on mobile
    Fix README for pyenv
2016-09-04 Fix admin and API namespace
    [PianetteApi.py]
2016-09-04 Fix exception when no selected source
    [main.py]
2016-09-04 Fix shameful typo 👹
    [Pianette.py]
2016-09-04 PianoState→Piano
2016-09-04 Fix KeyError's now that piano allows potentially more notes than in mappings
    [Pianette.py]
2016-09-05 Improve PCB files
    Work in progress, still to be tested in real life
    [AnalogTrigger.fzz, ArduinoBoard.fzz, BusBoard.fzz]
2016-09-18 Fix missing import for errors
    [Pianette.py]
2016-09-18 Refactor configuration parsing
    Add `select-player` as argument
    Import games as modules
    Provide an interface to create custom methods in game configuration
    Remove game-specific configs from top-level config directory
    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
    [Pianette.py, PianetteArgumentParser.py, PianetteCmd.py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]
2016-09-18 Factor things, add error handling
    [Pianette.py, PianetteArgumentParser.py, PianetteCmd.py]
2016-09-18 Add error handling for game selection
    [Pianette.py]
2016-09-19 Fixes #2 — manage empty lines
    [PianetteCmd.py]
2016-09-19 Small fixups, comments, blank lines
    [PianetteCmd.py]
2016-09-19 Fixes #4 — Add commands in the configuration
    [PianetteCmd.py]
2016-09-19 Move sources classes into /sources/
    Instantiante class in Pianette and not in main
    Fix enable-source/disable-source
    [Pianette.py, api.py, gpio.py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]
2016-09-19 Fix folder paths for API re: previous commit
    [api.py]
2016-09-25 Refactor get_buffered_states_for_controls_string()
    Make the method not static
    Add grammar parsing : | , {} through an `extract()` method
    Fix various bugs that did :
    - introduce a 1-cycle offset when collapsing time indexes
    - accept unsupported controls
    no BC breaks
    [Pianette.py]
2016-09-26 Add Street Fighter Alpha 3 Stages configuration
2016-09-26 [SFɑ3] Configure character positions
2016-09-26 `console.reset` → `game.reset`
2016-09-26 Remove console.reset command entirely
    [PianetteCmd.py]
2016-09-26 [SFɑ3] Attempt to sync broadcast game.reset
2016-09-26 [SFɑ3] Fix select-handicap
2016-09-26 time.sleep unit is now Pianette cycles — Adjust SFɑ3 sync
2016-09-26 [SFɑ3] Wet finger adjust start timings
2016-09-26 [SFɑ3] Better sync for game.start
2016-09-26 [SFɑ3] Choose random character, fix position of player 2 Rose
2016-09-26 [SFɑ3] Handicap select adjustment, stage should now match chosen
2016-09-26 [SFɑ3] Sync Player1/2 timings, add pause before stage select
2016-09-26 Fix mapping dictionary being unecessarily updated
    [Pianette.py]
2016-09-27 Fix pedal name case
2016-09-27 [SFɑ3] New notation for Ken/Ryu combos
2016-09-27 [SFɑ3] Tryout Dhalsim mappgins
2016-09-27 Fix case when no mappings available for player
    [Pianette.py]
2016-09-27 Fix normalization of piano arguments string
    [PianetteCmd.py]
2016-09-27 sustain pedal now uses symbol 𝆮
2016-09-27 [Cnk] Allow more time for choosing track
2016-09-27 Add default cycle period reset is not overriden
    [Pianette.py]
2016-09-27 [SFɑ3] Use actual note numbering, C3 through C6
2016-09-27 [SFɑ3] Bump up sleeping times a little
    Wet finger style
2016-09-28 [SFa3] Introducing game.flip
    Refactor revert_direction process into a method
    [PianetteCmd.py]
2016-09-28 Allow both ♯ and ♭ in piano notes. Substiture whole words only.
2016-09-28 [SFɑ3] Fierce strikes are now a combination of two strikes
2016-09-29 [SFɑ3] Remove chords that are way too out of our C major scale base
2016-09-29 [SFɑ3] Combos uplift incoming
2016-09-29 Fix broken arrow aliasing.
    [PianetteCmd.py]
2016-09-29 [SFɑ3] Add combos for character: Adon
2016-09-29 [SFɑ3] Add combos for character: Akuma
2016-09-29 [SFɑ3] Add combos for character: Birdie
2016-09-29 [SFɑ3] Add combos for character: Blanka
2016-09-29 [SFɑ3] Fix duplicate combos for character: Akuma
2016-09-29 [SFɑ3] Add combos for character: Cammy
2016-09-29 [SFɑ3] Adjust combos for characters: Birdie, Blanka
2016-09-29 [SFɑ3] Add combos for character: Charlie
2016-09-29 [SFɑ3] Fix duplicate combo for character: Charlie
2016-09-29 [SFɑ3] Add combos for character: Chun-Li
2016-09-29 [SFɑ3] Add combos for character: Cody
2016-09-29 [SFɑ3] Add combos for character: Dan
2016-09-29 [SFɑ3] Add combos for character: Dhalsim
2016-09-29 [SFɑ3] Add combos for character: E. Honda
2016-09-29 [SFɑ3] Add combos for character: Gen
2016-09-29 [SFɑ3] Fixup combos for character: Gen
2016-09-30 [SFɑ3] Add combos for character: Guy
2016-09-30 [SFɑ3] Add combos for character: Karin
2016-09-30 [SFɑ3] Adjust combos for character: Ken
2016-09-30 [SFɑ3] Add combos for character: M. Bison
2016-09-30 [SFɑ3] Add combos for character: R. Mika
2016-09-30 [SFɑ3] Add combos for character: Rolento
2016-09-30 [SFɑ3] Add combos for character: Rose
2016-09-30 [SFɑ3] Add combos for character: Ryu
2016-09-30 [SFɑ3] Add combos for character: Sagat
2016-09-30 [SFɑ3] Add combos for character: Sakura
2016-09-30 [SFɑ3] Add combos for character: Sodom
2016-09-30 [SFɑ3] Add combos for character: Vega
2016-09-30 [SFɑ3] Fixup combos for character: Vega
2016-09-30 [SFɑ3] Add combos for character: Zangief
2016-10-10 Add Weber piano hooks (MakerFaire NY 2016 pianos)
    [Export_WEBER_Left.stl, Export_WEBER_Right.stl, Hooks_Weber.CATPart]
2020-11-28 Update README — https is the new http
